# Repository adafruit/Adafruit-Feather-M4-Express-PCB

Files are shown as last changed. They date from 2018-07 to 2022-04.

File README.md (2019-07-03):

## Adafruit Feather M4 Express microcontroller board PCB

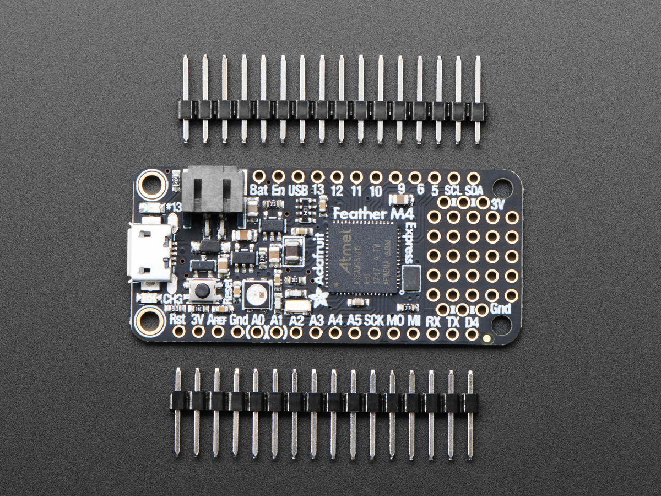
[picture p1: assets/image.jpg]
<a href="http://www.adafruit.com/products/3857"><br/>
Click here to purchase one from the Adafruit shop</a>

PCB files for the Adafruit Feather M4 Express. PCB format is EagleCAD schematic and board layout

For more details, check out the product pages at
* https://www.adafruit.com/products/3857

### Description

It's what you've been waiting for, the Feather M4 Express featuring ATSAMD51. This Feather is fast like a swift, smart like an owl, strong like a ox-bird (it's half ox, half bird, OK?) This feather is powered by our new favorite chip, the ATSAMD51J19 -  with its 120MHz Cortex M4 with floating point support and 512KB Flash and 192KB RAM. Your code will zig and zag and zoom, and with a bunch of extra peripherals for support, this will for sure be your favorite new chipset.

And best of all, it's a Feather - so you know it will work with all our FeatherWings! What a great way to quickly get up and running.

The most exciting part of the Feather M4 is that while you can use it with the Arduino IDE - and it's bonkers fast when you do, we are shipping it with CircuitPython on board. When you plug it in, it will show up as a very small disk drive with main.py on it. Edit main.py with your favorite text editor to build your project using Python, the most popular programming language. No installs, IDE or compiler needed, so you can use it on any computer, even ChromeBooks or computers you can't install software on. When you're done, unplug the Feather and your code will go with you.

### License

Adafruit invests time and resources providing this open source design, please support Adafruit and open-source hardware by purchasing products from [Adafruit](https://www.adafruit.com)!

Designed by Limor Fried/Ladyada for Adafruit Industries.

Creative Commons Attribution/Share-Alike, all text above must be included in any redistribution. See license.txt for additional details.

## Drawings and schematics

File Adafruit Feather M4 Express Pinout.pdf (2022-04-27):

# Adafruit Feather M4 Express

# https://www.adafruit.com/product/3857 The Microchip (nee Atmel) SAMD51 is an

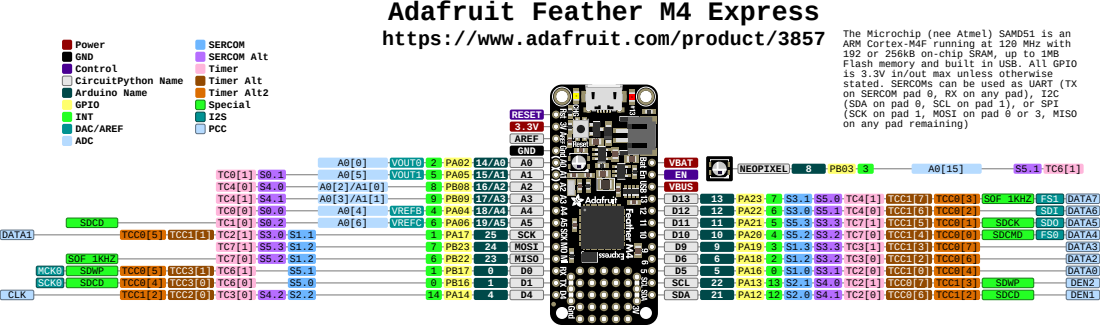
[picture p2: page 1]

ARM Cortex-M4F running at 120 MHz with
192 or 256kB on-chip SRAM, up to 1MB
Flash memory and built in USB. All GPIO
is 3.3V in/out max unless otherwise
stated. SERCOMs can be used as UART (TX
on SERCOM pad 0, RX on any pad), I2C
(SDA on pad 0, SCL on pad 1), or SPI
(SCK on pad 1, MOSI on pad 0 or 3, MISO
on any pad remaining)

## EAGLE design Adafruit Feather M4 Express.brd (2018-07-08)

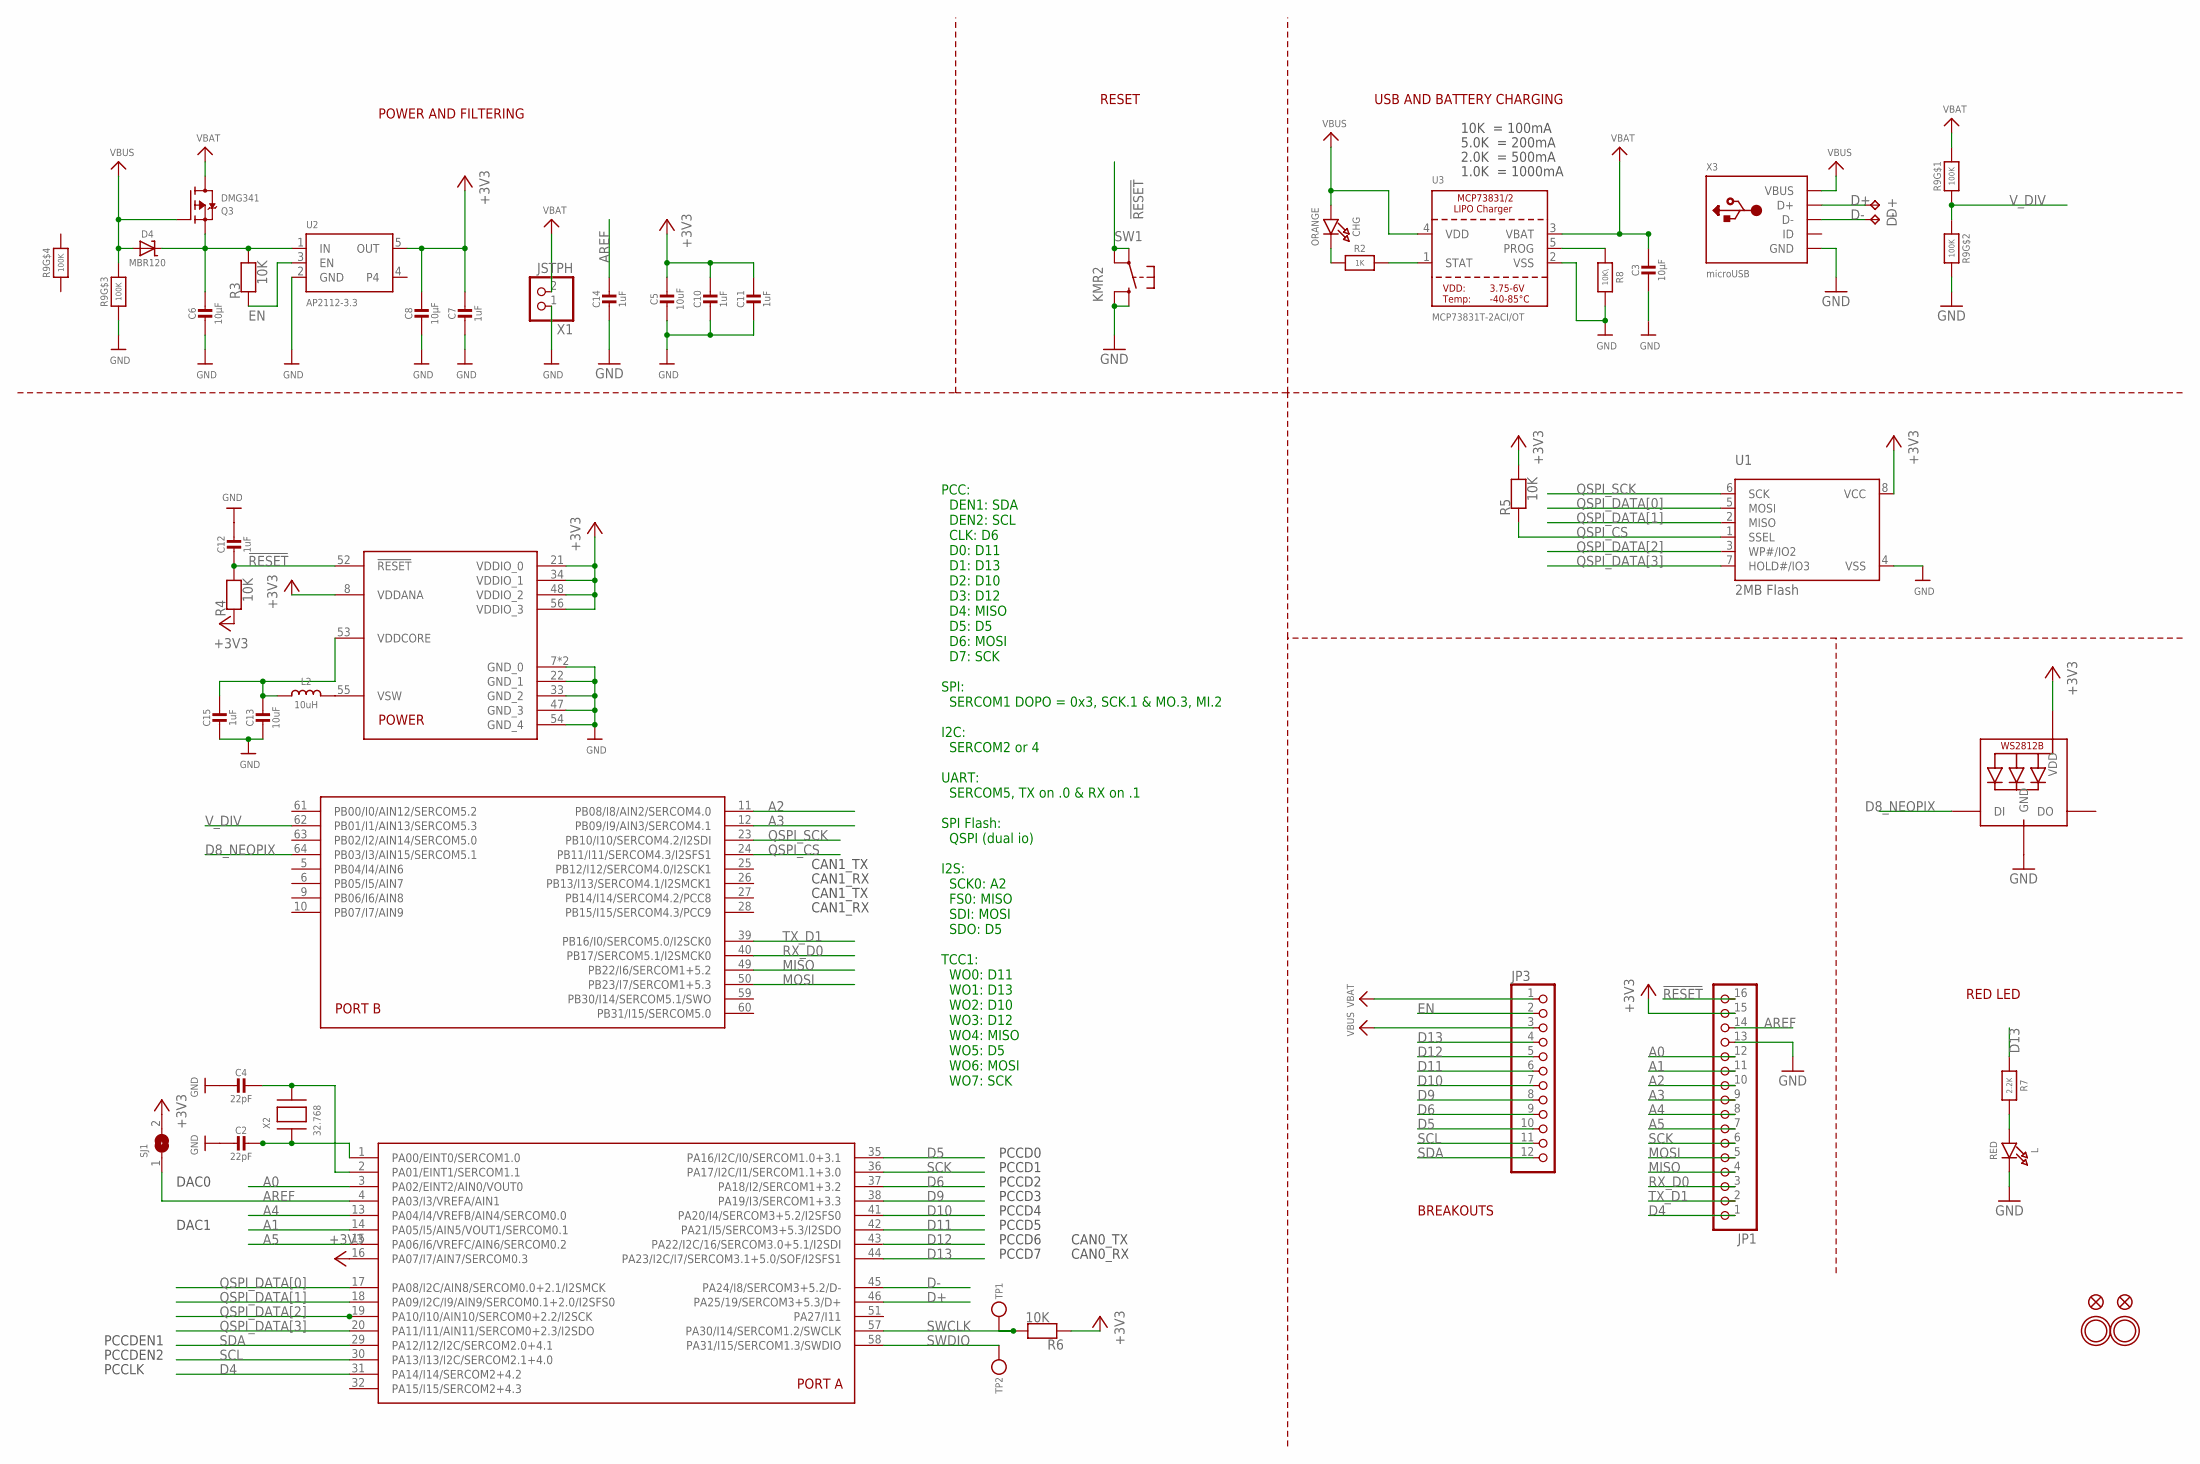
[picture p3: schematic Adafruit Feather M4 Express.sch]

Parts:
C2, C4: 22pF; 0603-NO
C3, C6, C8: 10µF; 0805-NO
C5, C13: 10uF; 0805-NO
C7, C10, C11, C12, C14, C15: 1uF; 0603-NO
CHG: ORANGE; CHIPLED_0805_NOOUTLINE
D4: MBR120; SOD-123
D+: TPB1,27; B1,27
D-: TPB1,27; B1,27
JP1: HEADER-1X16ROUND; 1X16_ROUND
JP3: HEADER-1X12; 1X12_ROUND
L: RED; CHIPLED_0805_NOOUTLINE
L2: 10uH; INDUCTOR_1007
LED1: WS2812B3535; LED3535
Q3: DMG341; SOT23-R
R2: 1K; 0603-NO
R3, R4, R5, R6: 10K; 0603-NO
R7: 2.2K; 0603-NO
R8: 10K\; 0603-NO
R9: 100K; RESPACK_4X0603_NO
SJ1: SOLDERJUMPERCLOSED; SOLDERJUMPER_CLOSEDWIRE
SW1: KMR2; BTN_KMR2_4.6X2.8
TP1, TP2: TESTPOINTROUND1.5MM; TESTPOINT_ROUND_1.5MM
U1: 2MB Flash; USON8
U2: AP2112-3.3; SOT23-5
U3: MCP73831T-2ACI/OT; SOT23-5
U$14: ATSAMD51J; PQFN64-1
U$31, U$32: MOUNTINGHOLE2.5; MOUNTINGHOLE_2.5_PLATED
U$34, U$35: FIDUCIAL_1MM
X1: JSTPH; JSTPH2
X2: 32.768; XTAL3215
X3: microUSB; 4UCONN_20329_V2

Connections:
!RESET: C12.2, JP1.16, R4.2, SW1.A, SW1.A' (P1), U$14.52 (!RESET)
+3V3: C5.1, C7.1, C8.1, C10.1, C11.1, JP1.15, LED1.2 (VDD), R4.1, R5.2, R6.1, SJ1.2, U1.8 (VCC), U2.5 (OUT), U$14.8 (VDDANA), U$14.16 (PA07/I7/AIN7/SERCOM0.3), U$14.21 (VDDIO_0), U$14.34 (VDDIO_1), U$14.48 (VDDIO_2), U$14.56 (VDDIO_3)
A0: JP1.12, U$14.3 (PA02/EINT2/AIN0/VOUT0)
A1: JP1.11, U$14.14 (PA05/I5/AIN5/VOUT1/SERCOM0.1)
A2: JP1.10, U$14.11 (PB08/I8/AIN2/SERCOM4.0)
A3: JP1.9, U$14.12 (PB09/I9/AIN3/SERCOM4.1)
A4: JP1.8, U$14.13 (PA04/I4/VREFB/AIN4/SERCOM0.0)
A5: JP1.7, U$14.15 (PA06/I6/VREFC/AIN6/SERCOM0.2)
AREF: C14.1, JP1.14, SJ1.1, U$14.4 (PA03/I3/VREFA/AIN1)
D4: JP1.1, U$14.31 (PA14/I14/SERCOM2+4.2)
D5: JP3.10, U$14.35 (PA16/I2C/I0/SERCOM1.0+3.1)
D6: JP3.9, U$14.37 (PA18/I2/SERCOM1+3.2)
D8_NEOPIX: LED1.1 (DI), U$14.64 (PB03/I3/AIN15/SERCOM5.1)
D9: JP3.8, U$14.38 (PA19/I3/SERCOM1+3.3)
D10: JP3.7, U$14.41 (PA20/I4/SERCOM3+5.2/I2SFS0)
D11: JP3.6, U$14.42 (PA21/I5/SERCOM3+5.3/I2SDO)
D12: JP3.5, U$14.43 (PA22/I2C/16/SERCOM3.0+5.1/I2SDI)
D13: JP3.4, R7.1, U$14.44 (PA23/I2C/I7/SERCOM3.1+5.0/SOF/I2SFS1)
D+: D+.TP, U$14.46 (PA25/19/SERCOM3+5.3/D+), X3.D+
D-: D-.TP, U$14.45 (PA24/I8/SERCOM3+5.2/D-), X3.D-
EN: JP3.2, R3.1, U2.3 (EN)
GND: C2.2, C3.2, C4.2, C5.2, C6.2, C7.2, C8.2, C10.2, C11.2, C12.1, C13.2, C14.2, C15.2, JP1.13, L.C, LED1.4 (GND), R8.2, R9.3 (1), R9.7 (2), SW1.B (S), SW1.B' (S1), U1.4 (VSS), U2.2 (GND), U3.2 (VSS), U$14.7 (GND_0), U$14.22 (GND_1), U$14.33 (GND_2), U$14.47 (GND_3), U$14.54 (GND_4), U$14.EXP (GND_0), X1.1, X3.BASE@1 (GND), X3.BASE@2 (GND), X3.GND, X3.SPRT@1 (GND), X3.SPRT@2 (GND), X3.SPRT@3 (GND), X3.SPRT@4 (GND)
MISO: JP1.4, U$14.49 (PB22/I6/SERCOM1+5.2)
MOSI: JP1.5, U$14.50 (PB23/I7/SERCOM1+5.3)
unnamed: CHG.C, R2.1
unnamed: L.A, R7.2
unnamed: R2.2, U3.1 (STAT)
unnamed: R8.1, U3.5 (PROG)
unnamed: C2.1, U$14.1 (PA00/EINT0/SERCOM1.0), X2.P$1
unnamed: C4.1, U$14.2 (PA01/EINT1/SERCOM1.1), X2.P$2
unnamed: L2.P$2 (2), U$14.55 (VSW)
QSPI_CS: R5.1, U1.1 (SSEL), U$14.24 (PB11/I11/SERCOM4.3/I2SFS1)
QSPI_DATA[0]: U1.5 (MOSI), U$14.17 (PA08/I2C/AIN8/SERCOM0.0+2.1/I2SMCK)
QSPI_DATA[1]: U1.2 (MISO), U$14.18 (PA09/I2C/I9/AIN9/SERCOM0.1+2.0/I2SFS0)
QSPI_DATA[2]: U1.3 (WP#/IO2), U$14.19 (PA10/I10/AIN10/SERCOM0+2.2/I2SCK)
QSPI_DATA[3]: U1.7 (HOLD#/IO3), U$14.20 (PA11/I11/AIN11/SERCOM0+2.3/I2SDO)
QSPI_SCK: U1.6 (SCK), U$14.23 (PB10/I10/SERCOM4.2/I2SDI)
RX_D0: JP1.3, U$14.40 (PB17/SERCOM5.1/I2SMCK0)
SCK: JP1.6, U$14.36 (PA17/I2C/I1/SERCOM1.1+3.0)
SCL: JP3.11, U$14.30 (PA13/I13/I2C/SERCOM2.1+4.0)
SDA: JP3.12, U$14.29 (PA12/I12/I2C/SERCOM2.0+4.1)
SWCLK: R6.2, TP1.P$1, U$14.57 (PA30/I14/SERCOM1.2/SWCLK)
SWDIO: TP2.P$1, U$14.58 (PA31/I15/SERCOM1.3/SWDIO)
TX_D1: JP1.2, U$14.39 (PB16/I0/SERCOM5.0/I2SCK0)
VBAT: C3.1, JP3.1, Q3.3 (D), R9.8 (2), U3.3 (VBAT), X1.2
VBUS: CHG.A, D4.A, JP3.3, Q3.1 (G), R9.6 (2), U3.4 (VDD), X3.VBUS
VDDCORE1: C13.1, C15.1, L2.P$1 (1), U$14.53 (VDDCORE)
VHI: C6.1, D4.C, Q3.2 (S), R3.2, U2.1 (IN)
V_DIV: R9.1, R9.2 (1), U$14.62 (PB01/I1/AIN13/SERCOM5.3)

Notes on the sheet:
POWER AND FILTERING
RESET
10K = 100mA
5.0K = 200mA
2.0K = 500mA
1.0K = 1000mA
USB AND BATTERY CHARGING
BREAKOUTS
RED LED
PCCDEN1
PCCDEN2
PCCD0
PCCD1
PCCD2
PCCD3
PCCD4
PCCD5
PCCD6
PCCD7
PCCLK
PCC: DEN1: SDA DEN2: SCL CLK: D6 D0: D11 D1: D13 D2: D10 D3: D12 D4: MISO D5: D5 D6: MOSI D7: SCK SPI: SERCOM1 DOPO = 0x3, SCK.1 & MO.3, MI.2 I2C: SERCOM2 or 4 UART: SERCOM5, TX on .0 & RX on .1 SPI Flash: QSPI (dual io) I2S: SCK0: A2 FS0: MISO SDI: MOSI SDO: D5 TCC1: WO0: D11 WO1: D13 WO2: D10 WO3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
CAN0_TX
CAN0_RX
DAC0
DAC1
CAN1_TX
CAN1_RX

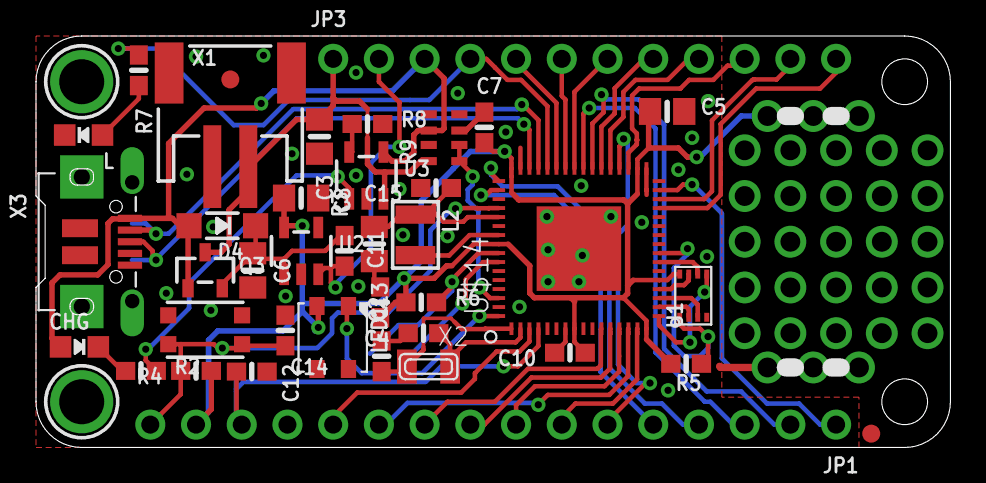
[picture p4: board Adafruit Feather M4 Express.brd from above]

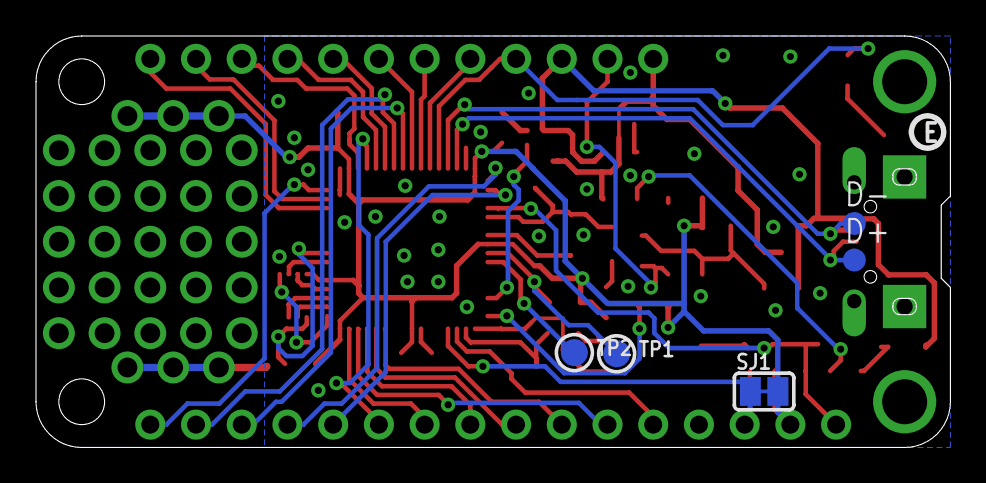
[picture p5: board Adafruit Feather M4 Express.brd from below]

Board: 2 copper layers, 50.8 x 22.9 mm, 49 parts (7 on the bottom side), 49 nets.

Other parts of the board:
U$5: FEATHERM4_BOT
U$6: FEATHERM4_TOP
U$13: PCBFEAT-REV-040

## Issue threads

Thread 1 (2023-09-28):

extraneous "\" in value for R8

salfter, 2023-09-28:
I wanted to make a 3D model of this board for mechanical integration purposes, so I imported it into KiCad, attached 3D models to the various components, and tried importing the board into FreeCAD with its KiCad Step Up plugin.  It threw an error, described at https://github.com/easyw/kicadStepUpMod/issues/185.  The value field for R8 is set to "10K\"...note the backslash that shouldn't be there.  Removing the backslash allowed the board to be imported into FreeCAD.

I'd submit a revised PCB file with this ticket, but I use KiCad, not EAGLE.

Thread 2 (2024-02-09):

SPI pinout

gutzchi, 2024-02-09:
I am designing a PCB that will use this board and I might have found a small error on the pinout. On the schematic, the DOPO field on the CTRLA registers of the SERCOM1 register is configured as 0x03, and thus SERCOM1.1 is selected as SCK and so on.

However, this value is reserved in the SAMD51 and it should not be possible to have the SCK on this pin:
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

I believe this error has been inherited from the previous board, which uses the SAMD21, where this value is not reserved and the pinout is correct. On the Grand Central M4, which also uses the SAMD51, the pinout is correct.

If I am right SPI should not be able to work with the current pinout, did you have any trouble with it?

Kind regards from the Netherlands.
Gustavo.

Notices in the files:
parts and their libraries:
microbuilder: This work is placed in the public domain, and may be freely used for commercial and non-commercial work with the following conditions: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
